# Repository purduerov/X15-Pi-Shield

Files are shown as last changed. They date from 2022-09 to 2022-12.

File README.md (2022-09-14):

# Readme for X15-Pi-Shield

Whenever you make a new part, download the datasheet and save it here _**and**_ with the part in the parts library

Always pull other people's changes before beginning to work
`git pull`

Be sure to push your changes after  working on them. Run:
1. `git add .` to add any files in this directory or a subdirectory
or `git add -u` to add any modified files
2. (Optional) `git clean -nX` to see what ignored files can be removed
	`git clean -fX` removes ignored files (Eagle backups)
3. `git commit -m "helpful commit message"` with a description of the work that you did
4. `git push` to push your work to github

Other helpful commands
* `git status` says information about modified and staged files
* `git log` shows the recent commits of the repository
* `git log filename.extension` show the recent commits for just that file
* `git checkout first-couple-letter-of-commit-id` lets you go back to a previous version
* `git checkout master` brings you back to the latest commit
* `git tag` lists the tags
* `git tag -a orderX -m "the version of the board placed for the X'th order"` tag a specific commit
* `git push --tags` needed to push tags to remote
* `git show orderX` show the commit log for the given tag
* `git checkout orderX` go back and interact with the files at the tagged commit

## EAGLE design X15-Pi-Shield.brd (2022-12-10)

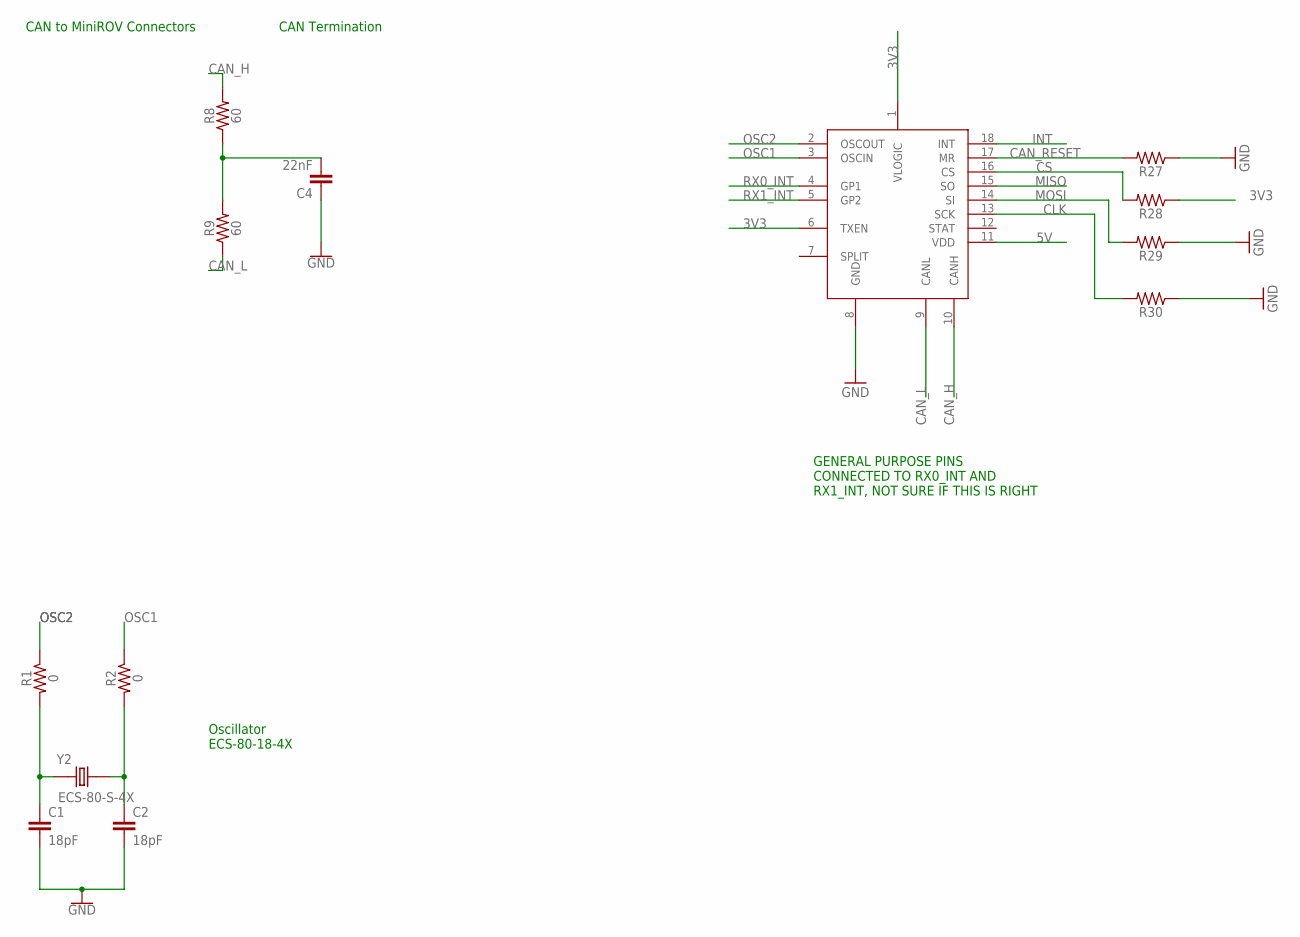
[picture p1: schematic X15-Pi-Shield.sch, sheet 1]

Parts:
C1, C2: 18pF; 0603
C4: 22nF; 0603
R1, R2: 0; 0603
R8, R9: 60; 0603
R27, R28, R29, R30: 50k; 0603
U$6: HI-3110; SOIC-18
Y2: ECS-80-S-4X; XTAL_ECS-80-S-4X

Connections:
3V3: R28.1, U$6.1 (VLOGIC), U$6.6 (TXEN); also elsewhere on the board
5V: U$6.11 (VDD); also elsewhere on the board
CAN_H: R8.2, U$6.10 (CANH); also elsewhere on the board
CAN_L: R9.1, U$6.9 (CANL); also elsewhere on the board
CAN_RESET: R27.2, U$6.17 (MR); also elsewhere on the board
CLK: R30.2, U$6.13 (SCK); also elsewhere on the board
CS: R28.2, U$6.16 (CS); also elsewhere on the board
GND: C1.2, C2.2, C4.1, R27.1, R29.1, R30.1, U$6.8 (GND); also elsewhere on the board
INT: U$6.18 (INT); also elsewhere on the board
MISO: U$6.15 (SO); also elsewhere on the board
MOSI: R29.2, U$6.14 (SI); also elsewhere on the board
unnamed: C1.1, R1.2, Y2.1
unnamed: C2.1, R2.2, Y2.2
unnamed: C4.2, R8.1, R9.2
OSC1: R2.1, U$6.3 (OSCIN)
OSC2: R1.1, U$6.2 (OSCOUT)
RX0_INT: U$6.4 (GP1); also elsewhere on the board
RX1_INT: U$6.5 (GP2); also elsewhere on the board

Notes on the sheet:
Oscillator ECS-80-18-4X
CAN Termination
CAN to MiniROV Connectors
GENERAL PURPOSE PINS CONNECTED TO RX0_INT AND RX1_INT, NOT SURE IF THIS IS RIGHT

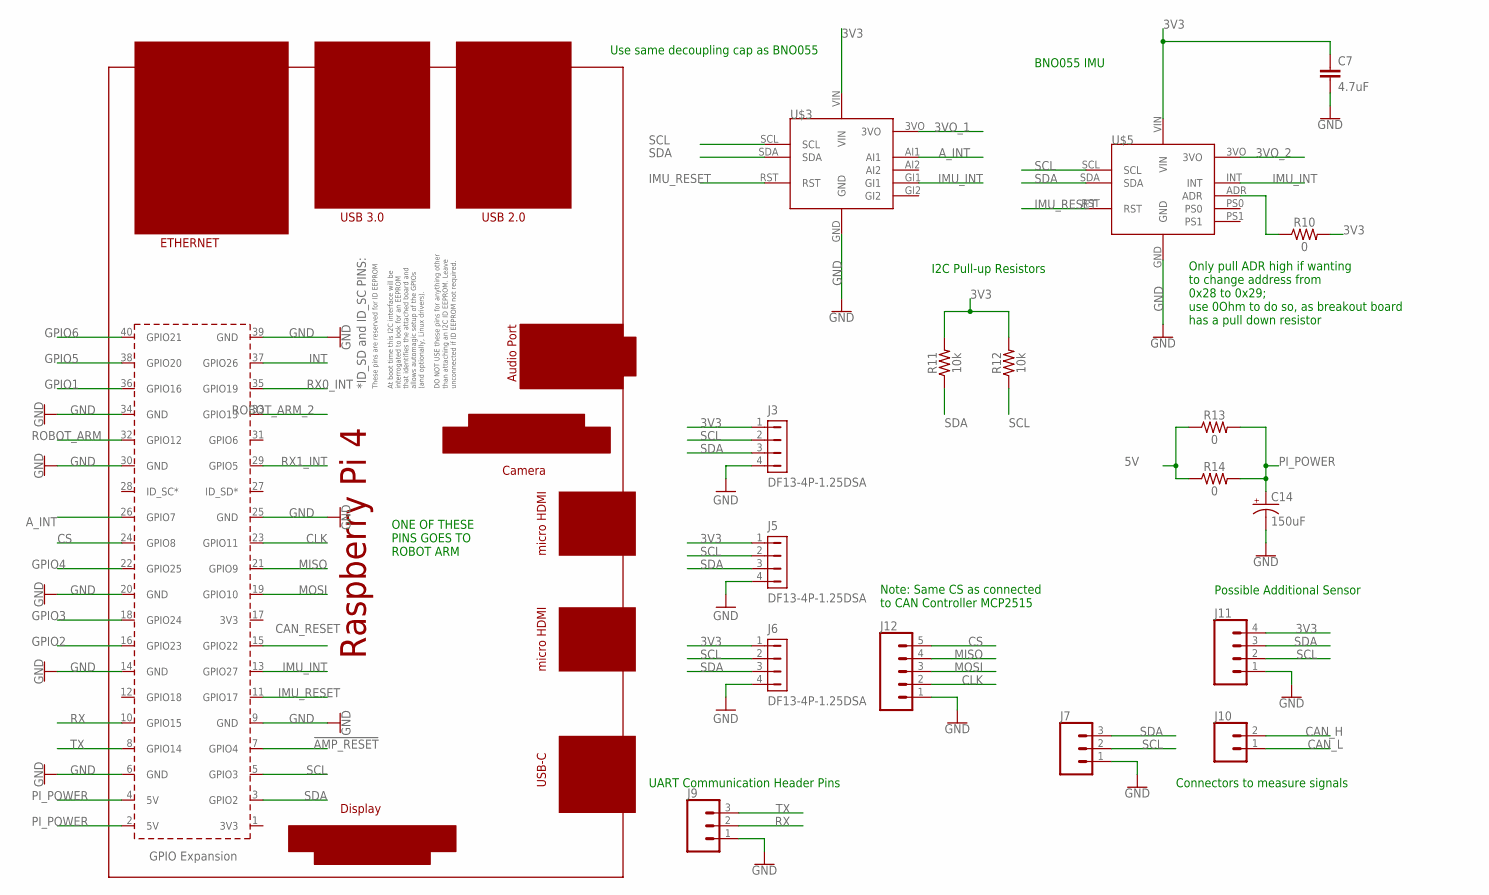
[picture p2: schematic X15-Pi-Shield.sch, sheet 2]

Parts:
C7: 4.7uF; 0603
C14: 150uF; 2917(7343-31-METRIC)
J3, J5, J6: DF13-4P-1.25DSA
J7, J9: CONN_03; 1X03
J10: CONN_02; 1X02
J11: CONN_04; 1X04
J12: CONN_05; 1X05
R10, R13, R14: 0; 0603
R11, R12: 10k; 0603
U$3: ADAFRUIT-FXOS8700-FXAS21002
U$4: RPI4
U$5: ADAFRUIT-BNO055

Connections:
3V3: C7.1, J3.1, J5.1, J6.1, J11.4, R10.2, R11.2, R12.2, U$3.VIN, U$5.VIN; also elsewhere on the board
3VO_1: U$3.3VO
3VO_2: U$5.3VO
5V: R13.1, R14.1; also elsewhere on the board
!AMP_RESET: U$4.7 (GPIO4); also elsewhere on the board
A_INT: U$3.AI1, U$4.26 (GPIO7)
CAN_H: J10.2; also elsewhere on the board
CAN_L: J10.1; also elsewhere on the board
CAN_RESET: U$4.15 (GPIO22); also elsewhere on the board
CLK: J12.2, U$4.23 (GPIO11); also elsewhere on the board
CS: J12.5, U$4.24 (GPIO8); also elsewhere on the board
GND: C7.2, C14.-, J3.4, J5.4, J6.4, J7.1, J9.1, J11.1, J12.1, U$3.GND, U$4.6 (GND), U$4.9 (GND), U$4.14 (GND), U$4.20 (GND), U$4.25 (GND), U$4.30 (GND), U$4.34 (GND), U$4.39 (GND), U$5.GND; also elsewhere on the board
GPIO1: U$4.36 (GPIO16); also elsewhere on the board
GPIO2: U$4.16 (GPIO23); also elsewhere on the board
GPIO3: U$4.18 (GPIO24); also elsewhere on the board
GPIO4: U$4.22 (GPIO25); also elsewhere on the board
GPIO5: U$4.38 (GPIO20); also elsewhere on the board
GPIO6: U$4.40 (GPIO21); also elsewhere on the board
IMU_INT: U$3.GI1, U$4.13 (GPIO27), U$5.INT
IMU_RESET: U$3.RST, U$4.11 (GPIO17), U$5.RST
INT: U$4.37 (GPIO26); also elsewhere on the board
MISO: J12.4, U$4.21 (GPIO9); also elsewhere on the board
MOSI: J12.3, U$4.19 (GPIO10); also elsewhere on the board
unnamed: R10.1, U$5.ADR
PI_POWER: C14.+, R13.2, R14.2, U$4.2 (5V), U$4.4 (5V)
ROBOT_ARM: U$4.32 (GPIO12); also elsewhere on the board
ROBOT_ARM_2: U$4.33 (GPIO13); also elsewhere on the board
RX: J9.2, U$4.10 (GPIO15)
RX0_INT: U$4.35 (GPIO19); also elsewhere on the board
RX1_INT: U$4.29 (GPIO5); also elsewhere on the board
SCL: J3.2, J5.2, J6.2, J7.2, J11.2, R12.1, U$3.SCL, U$4.5 (GPIO3), U$5.SCL; also elsewhere on the board
SDA: J3.3, J5.3, J6.3, J7.3, J11.3, R11.1, U$3.SDA, U$4.3 (GPIO2), U$5.SDA; also elsewhere on the board
TX: J9.3, U$4.8 (GPIO14)

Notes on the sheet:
UART Communication Header Pins
Note: Same CS as connected to CAN Controller MCP2515
Possible Additional Sensor
Connectors to measure signals
Use same decoupling cap as BNO055
I2C Pull-up Resistors
BNO055 IMU
Only pull ADR high if wanting to change address from 0x28 to 0x29; use 0Ohm to do so, as breakout board has a pull down resistor
ONE OF THESE PINS GOES TO ROBOT ARM

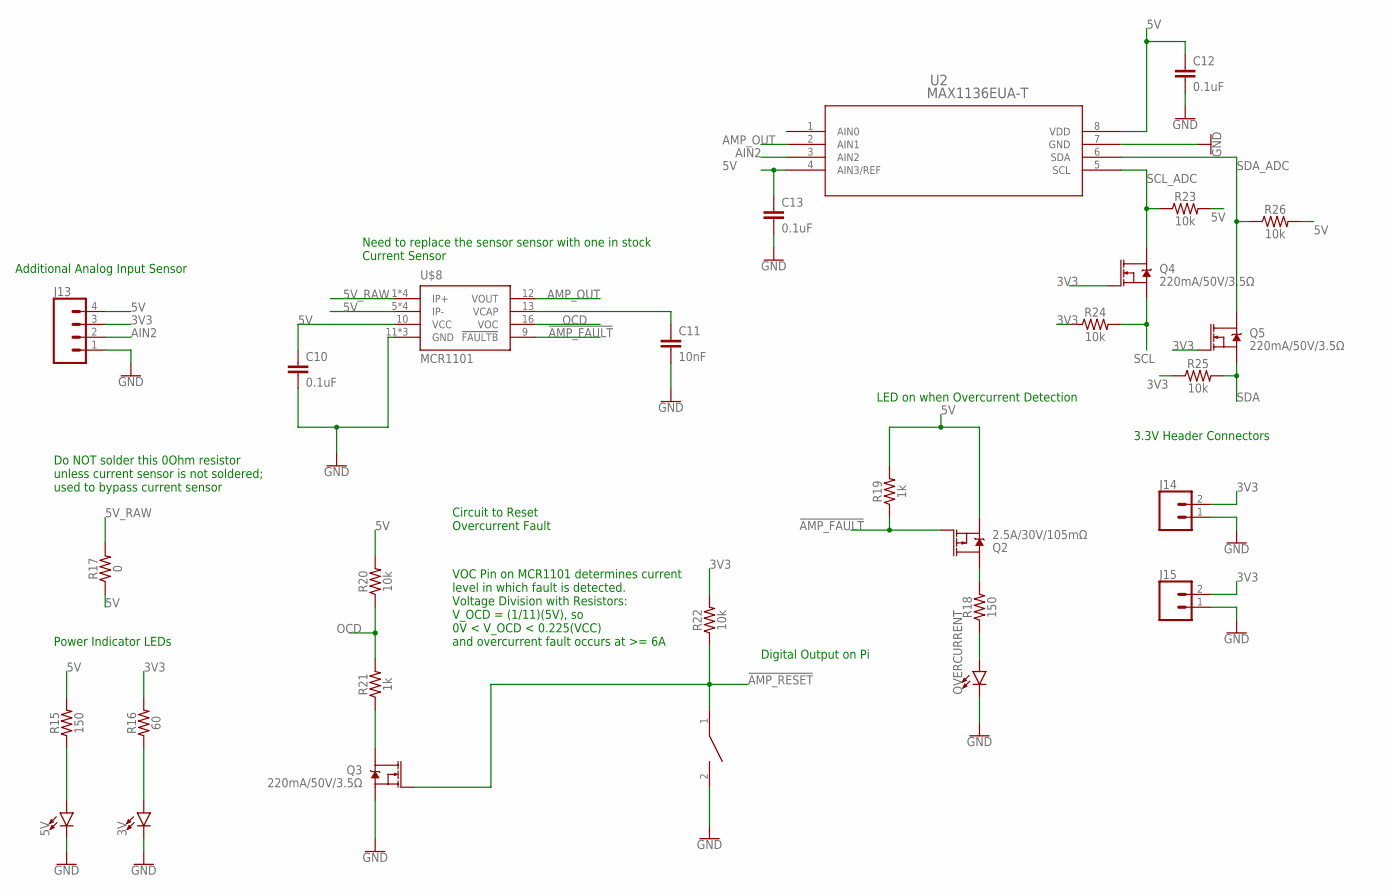
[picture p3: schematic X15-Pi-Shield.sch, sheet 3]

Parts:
3V, 5V: LED0603; LED-0603
C10, C12, C13: 0.1uF; 0603
C11: 10nF; 0603
J13: CONN_04; 1X04
J14, J15: CONN_02; 1X02
OVERCURRENT: LED0603; LED-0603
Q2: 2.5A/30V/105mΩ; SOT23-3
Q3, Q4, Q5: 220mA/50V/3.5Ω; SOT23-3
R15, R18: 150; 0603
R16: 60; 0603
R17: 0; 0603
R19, R21: 1k; 0603
R20, R22, R23, R24, R25, R26: 10k; 0603
U2: MAX1136EUA-T; 21-0036K
U$7: DISCRETECOMPONENTS_SWITCH; DISCRETECOMPONENTS_SW_2512
U$8: MCR1101; SOIC-16

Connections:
3V3: J13.3, J14.2, J15.2, Q4.1 (G), Q5.1 (G), R16.2, R22.2, R24.1, R25.1; also elsewhere on the board
5V: C10.1, C12.1, C13.1, J13.4, Q2.2 (S), R15.2, R17.1, R19.2, R20.2, R23.2, R26.2, U2.4 (AIN3/REF), U2.8 (VDD), U$8.5 (IP-), U$8.6 (IP-), U$8.7 (IP-), U$8.8 (IP-), U$8.10 (VCC); also elsewhere on the board
5V_RAW: R17.2, U$8.1 (IP+), U$8.2 (IP+), U$8.3 (IP+), U$8.4 (IP+)
!AMP_FAULT: Q2.1 (G), R19.1, U$8.9 (!FAULTB)
!AMP_RESET: Q3.1 (G), R22.1, U$7.1; also elsewhere on the board
AIN2: J13.2, U2.3 (AIN2)
AMP_OUT: U2.2 (AIN1), U$8.12 (VOUT)
GND: 3V.C, 5V.C, C10.2, C11.2, C12.2, C13.2, J13.1, J14.1, J15.1, OVERCURRENT.C, Q3.2 (S), U2.7 (GND), U$7.2, U$8.11 (GND), U$8.14 (GND), U$8.15 (GND); also elsewhere on the board
unnamed: 5V.A, R15.1
unnamed: 3V.A, R16.1
unnamed: C11.1, U$8.13 (VCAP)
unnamed: Q2.3 (D), R18.2
unnamed: OVERCURRENT.A, R18.1
unnamed: Q3.3 (D), R21.1
OCD: R20.1, R21.2, U$8.16 (VOC)
SCL: Q4.2 (S), R24.2; also elsewhere on the board
SCL_ADC: Q4.3 (D), R23.1, U2.5 (SCL)
SDA: Q5.2 (S), R25.2; also elsewhere on the board
SDA_ADC: Q5.3 (D), R26.1, U2.6 (SDA)

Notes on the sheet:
Do NOT solder this 0Ohm resistor unless current sensor is not soldered; used to bypass current sensor
Power Indicator LEDs
Additional Analog Input Sensor
3.3V Header Connectors
LED on when Overcurrent Detection
Circuit to Reset Overcurrent Fault
VOC Pin on MCR1101 determines current level in which fault is detected. Voltage Division with Resistors: V_OCD = (1/11)(5V), so 0V < V_OCD < 0.225(VCC) and overcurrent fault occurs at >= 6A
Digital Output on Pi
Need to replace the sensor sensor with one in stock Current Sensor

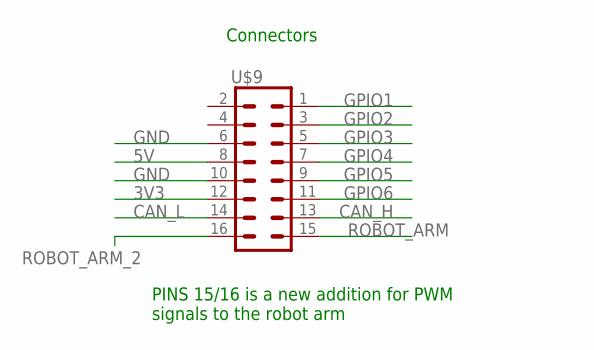
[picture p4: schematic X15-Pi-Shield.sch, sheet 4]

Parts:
U$9: 8X_CONN; IPL7X2

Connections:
3V3: U$9.12 (23); also elsewhere on the board
5V: U$9.8 (19); also elsewhere on the board
CAN_H: U$9.13 (1); also elsewhere on the board
CAN_L: U$9.14 (2); also elsewhere on the board
GND: U$9.6 (17), U$9.10 (21); also elsewhere on the board
GPIO1: U$9.1 (14); also elsewhere on the board
GPIO2: U$9.3 (16); also elsewhere on the board
GPIO3: U$9.5 (18); also elsewhere on the board
GPIO4: U$9.7 (20); also elsewhere on the board
GPIO5: U$9.9 (22); also elsewhere on the board
GPIO6: U$9.11 (24); also elsewhere on the board
ROBOT_ARM: U$9.15 (4); also elsewhere on the board
ROBOT_ARM_2: U$9.16 (3); also elsewhere on the board

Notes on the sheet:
Connectors
PINS 15/16 is a new addition for PWM signals to the robot arm

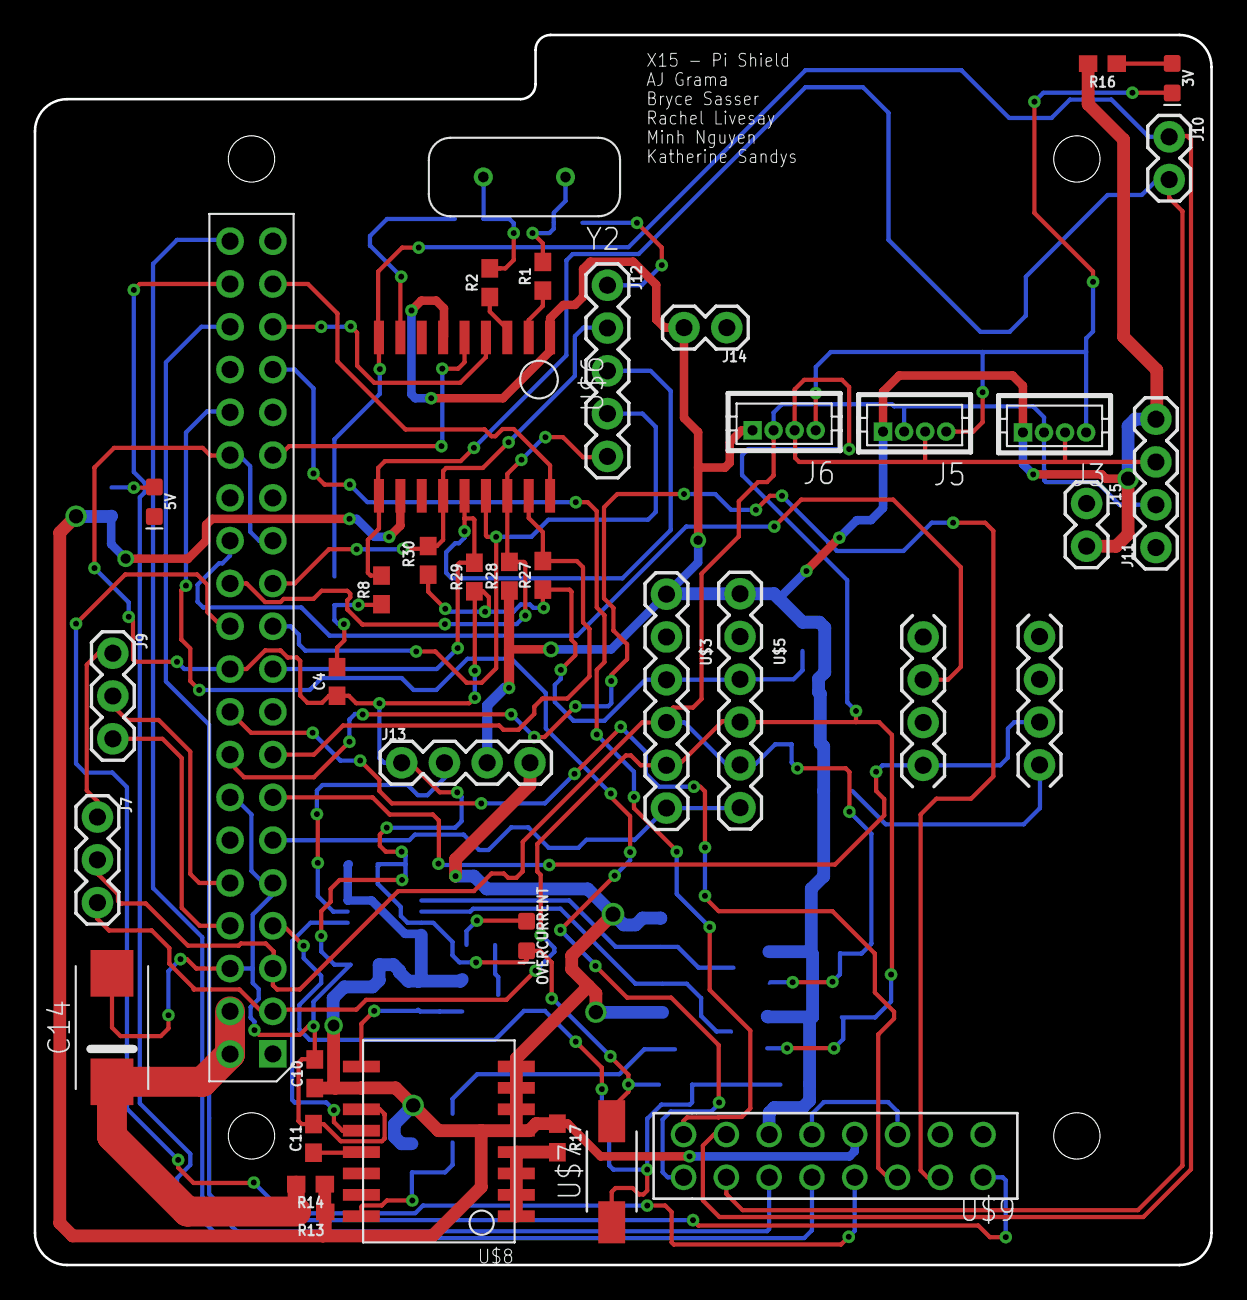
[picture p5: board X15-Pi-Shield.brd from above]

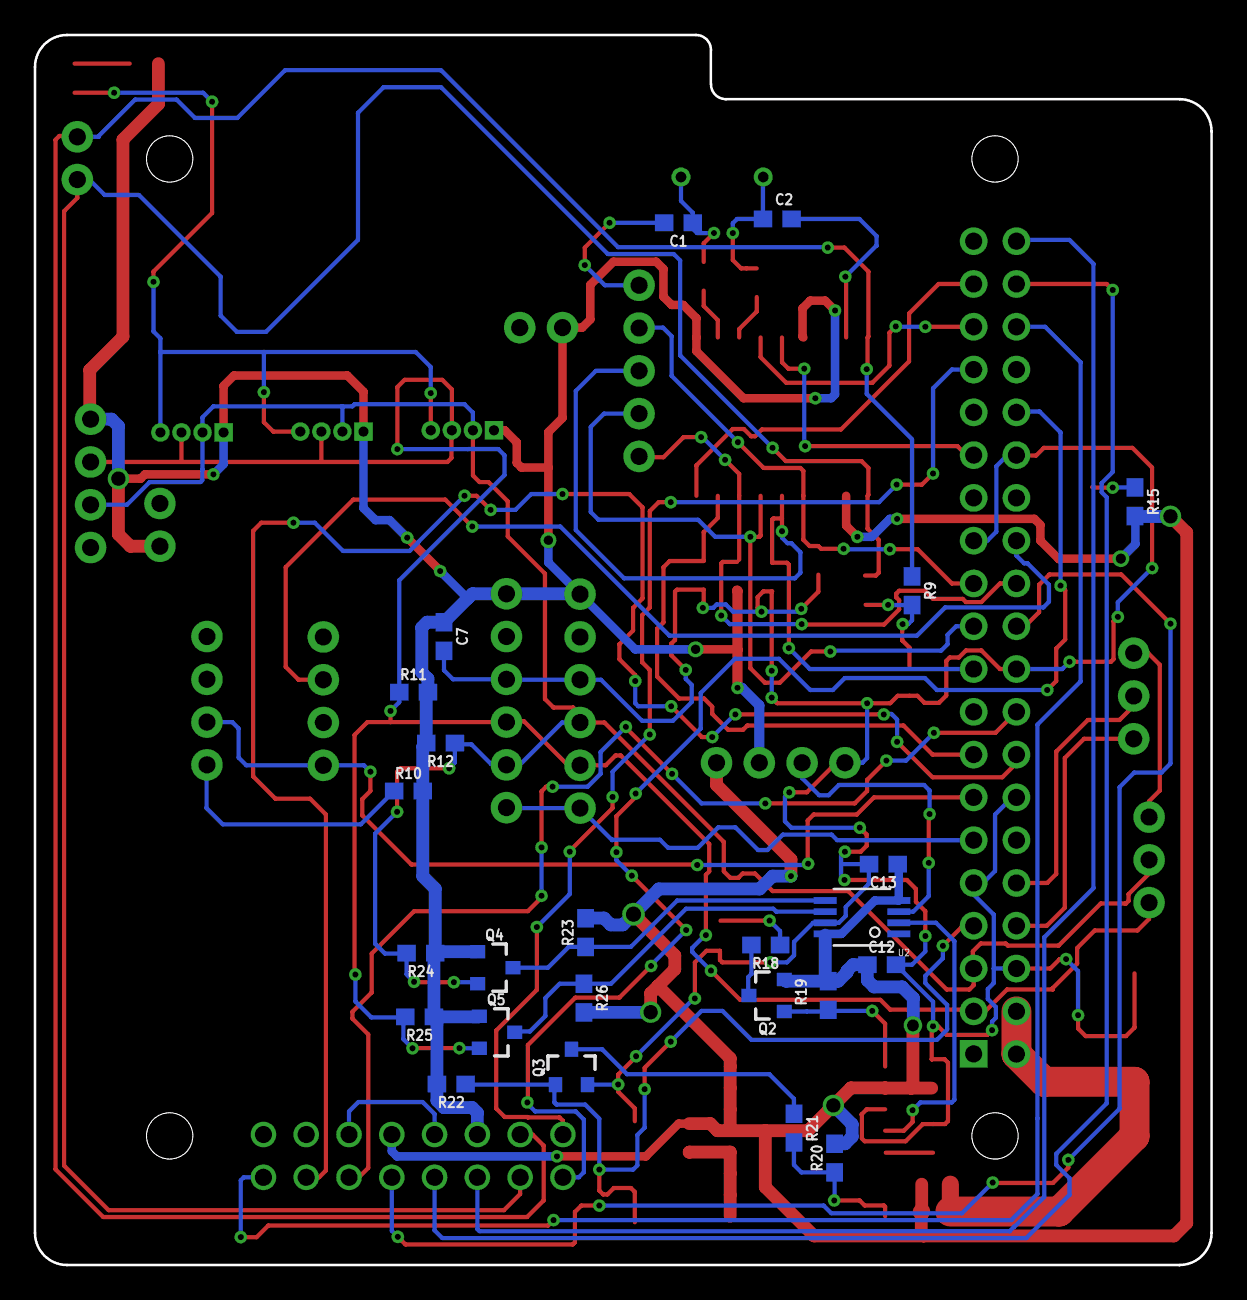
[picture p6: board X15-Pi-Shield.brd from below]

Board: 2 copper layers, 69.8 x 73.0 mm, 61 parts (24 on the bottom side), 49 nets.

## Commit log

2022-09-21 Starting Board
    [X15-Pi-Shield.brd]
2022-09-21 Empty starting board + schematic
    [X15-Pi-Shield.sch]
2022-10-15 First Schematic Draft
2022-10-15 First Schematic
2022-10-15 fixed ground and parts library
    [X15-Pi-Shield.sch]
2022-10-15 2nd try
    [X15-Pi-Shield.brd]
2022-10-15 Board Dimensions
    [X15-Pi-Shield.brd]
2022-10-22 help me mr. bryce sir
    [X15-Pi-Shield.sch]
2022-10-22 please help bryce
    [X15-Pi-Shield.brd]
2022-10-22 hi bryce
    [X15-Pi-Shield.brd]
2022-10-26 Board Dimensions AGAIN
    [X15-Pi-Shield.brd]
2022-11-05 I'm slowly losing my mind
    [X15-Pi-Shield.brd, X15-Pi-Shield.sch]
2022-12-01 Hi Katherine
    [X15-Pi-Shield.brd, X15-Pi-Shield.sch]
2022-12-03 I swear its good this time
    [X15-Pi-Shield.brd]
2022-12-08 HI :D
    [X15-Pi-Shield.brd, X15-Pi-Shield.sch]
2022-12-10 Names n Picture
    [X15-Pi-Shield.brd]

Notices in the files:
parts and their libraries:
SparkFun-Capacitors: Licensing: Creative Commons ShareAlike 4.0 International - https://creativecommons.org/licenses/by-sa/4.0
